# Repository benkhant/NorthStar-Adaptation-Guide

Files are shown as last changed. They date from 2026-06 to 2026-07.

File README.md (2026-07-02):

# NorthStar Adaptation Guide

> ⚠ Work in Progress: Hardware prototype complete. Documentation and software modules under active development.

### A Practical Guide to Building and Documenting a Low-Cost Open-Source Optical See-Through AR Headset

This repository documents the adaptation of Project North Star into a low-cost, reproducible, and well-documented optical see-through augmented reality (OST-AR) headset for computing education. The project establishes a transparent hardware and calibration foundation to support future development of interactive AR learning software.

Rather than focusing solely on hardware construction, this project emphasizes systematic documentation of the entire build process to lower financial and technical barriers to classroom deployment and future AR software development.

---

## Why This Project?

Commercial optical see-through AR headsets remain costly, proprietary, and difficult to deploy in classroom settings. This project aims to lower those barriers by providing a transparent, replicable, and well-documented alternative specifically tailored for computing education.

---

## Project Goals

- Adapt an open-source AR headset for educational use  
- Provide clear mechanical assembly documentation  
- Develop a repeatable optics calibration workflow  
- Publish a transparent bill of materials with cost breakdown  
- Enable reproducibility for educators and researchers  
- Establish a hardware foundation for interactive AR learning software
- Develop interactive AR learning activities for computer science education
- Evaluate the effectiveness of AR spatial visualization for teaching linked list operations

---

## Hardware Assembly

This guide is under active development. The headstrap assembly section will be added in a future update.

Mechanical assembly instructions are available here:

[Hardware Assembly Guide](docs/hardware-assembly.md)

Includes:
- Required components
- Heat insert installation
- Cable routing
- Display mounting
- Troubleshooting notes

---

## Optics Calibration

Calibration documentation is available here:

[Optics Calibration Guide](docs/optics-calibration.md)

Includes:
- Checkerboard-based alignment procedure
- Distortion correction process
- Representative calibration results
- Troubleshooting guide

---

## 3D-Printable Components

All printable components are located in:

[3D Printing Files](3d-printing-stl)

Each component is provided as an STL file for direct printing.

---

## Cost Transparency

This build prioritizes affordability using:
- Commodity electronics
- 3D-printed structural parts
- Open-source design

Filament costs are calculated using:
- Slicer-reported filament weight (grams)
- Cost per gram (based on spool price)
- Total print cost per component

A detailed bill of materials and cost breakdown spreadsheet will be published in this repository to support reproducibility.

---

## Current Status

- ✅ Hardware prototype constructed
- ✅ Optics calibration workflow established  
- 🚧 Mechanical documentation in progress  
- ✅ AR linked list deletion activity complete (Unity 2022)
- ✅ AR linked list deletion activity ported to Unity 6
- 🚧 Classroom pilot evaluation planned  

---

## Software: AR Linked List Deletion Activity

An interactive AR learning activity has been developed for visualizing 
linked list pointer operations using image tracking on an Android tablet.

Two versions of the activity are available in this repository:

| Version | Folder | Unity Version | Status |
|---|---|---|---|
| Stable (v1.0) | [`software/`](software/) | Unity 2022.3 LTS | ✅ Fully working, tagged `v1.0-deletion-activity` |
| Unity 6 Rebuild (v2.0) | [`LinkedListAR_Unity6/`](LinkedListAR_Unity6/) | Unity 6 (6000.0.73f1 LTS) | ✅ Fully working, tagged `v2.0-unity6-rebuild` |

### How It Works
Students physically manipulate printed marker cards on a table.
The tablet camera detects the cards and augments the scene with:
- Blue numbered nodes floating above each node card
- Orange dots above tail cards (outgoing pointers)
- Purple dots above head cards (incoming connections)
- Green arrows for correct pointer connections
- Red arrows for incorrect connections
- Live task instructions guiding students through the deletion task

### Activity Flow
1. Place all three node cards (10, 20, 30) on the table
2. Connect tail and head cards to build the starting list: 10 → 20 → 30
3. Delete node 20 by moving tail_10 to head_30, redirecting the pointer
4. The list updates to: 10 → 30

### Requirements
- Unity 2022.3 LTS (for `software/`) or Unity 6 6000.0.73f1 LTS (for `LinkedListAR_Unity6/`)
- AR Foundation
- Google ARCore XR Plugin
- Android tablet with ARCore support (tested on Samsung SM-X210)
- 7 printed marker cards (see `software/Assets/Markers/` or `LinkedListAR_Unity6/Assets/Markers/`)

### Unity 6 Migration Notes
The Unity 6 rebuild was created from scratch using Unity's AR Mobile template rather than migrating the Unity 2022 project directly. Key changes include:

- **ARCore added event fallback:** ARCore sometimes skips the `added` event for previously seen markers and fires `updated` directly. A fallback was added inside `UpdateMarker` to spawn objects on the spot if they don't exist yet, ensuring reliable detection across repeated app launches.
- **AR Mobile template:** Using the AR Mobile template instead of a generic Unity 6 project ensures correct renderer, AR Camera Background, OpenGLES3, and Tracked Pose Driver bindings are configured from the start.
- **API migration:** Updated from the deprecated `trackedImagesChanged` event to the new `trackablesChanged` UnityEvent introduced in AR Foundation 6.0.

### Current Status
- ✅ Image tracking with 7 marker cards
- ✅ Dynamic arrow drawing with color feedback
- ✅ Task instruction system
- ✅ Node deletion activity fully working on Unity 2022 and Unity 6
- 🚧 Esky HMD integration in progress
- 🚧 Classroom pilot evaluation planned

---

## Acknowledgements

Inspired by Project North Star.

Developed at Bucknell University.

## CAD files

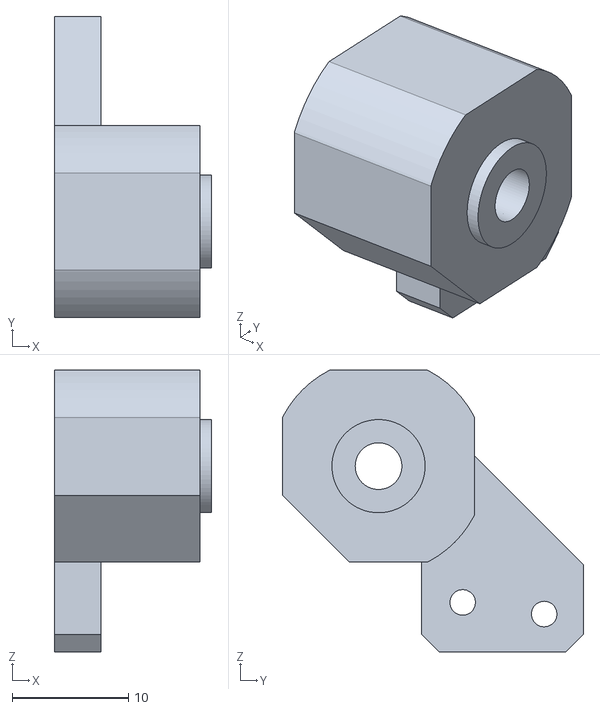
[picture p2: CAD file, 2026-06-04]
3d-printing-stl/strap_adapter_1_left.stl
13.5 x 25.8 x 24.2

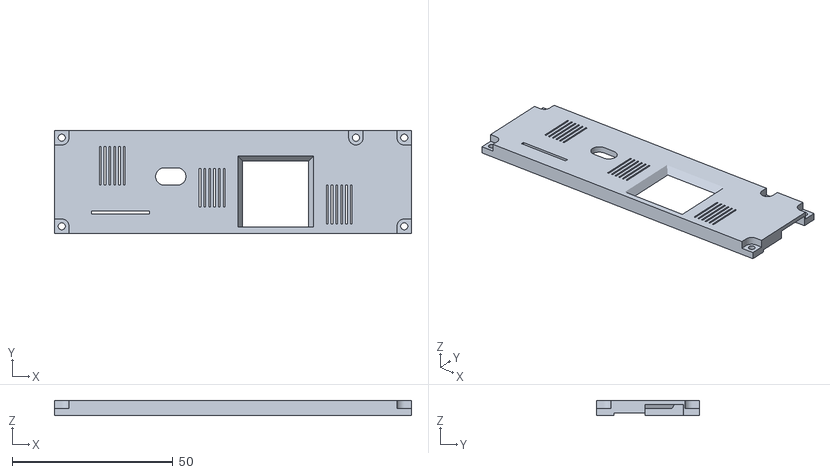
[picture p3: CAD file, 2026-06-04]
3d-printing-stl/electronic_lid.stl
110.9 x 32.0 x 4.80

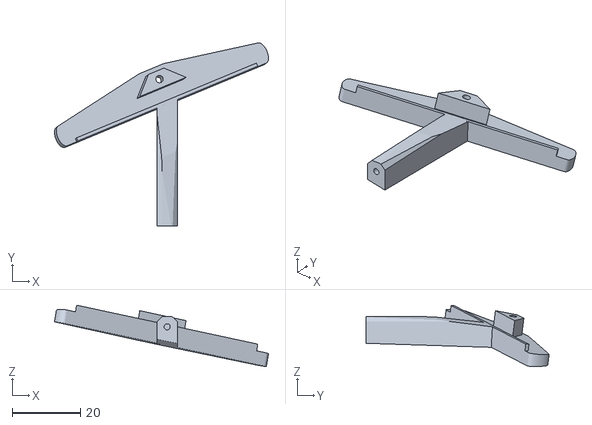
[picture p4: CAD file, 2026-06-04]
3d-printing-stl/display_holder_right.stl
62.7 x 53.7 x 17.9

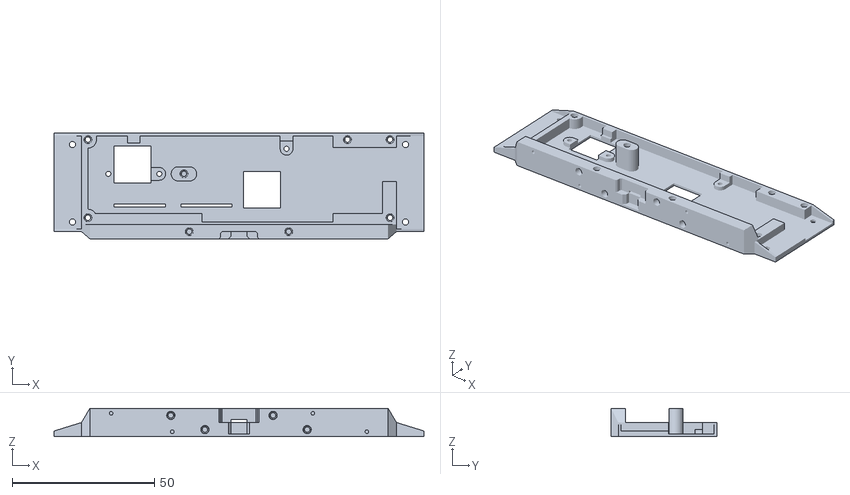
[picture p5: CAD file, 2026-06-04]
3d-printing-stl/electronic_bay.stl
130.2 x 37.2 x 10.0

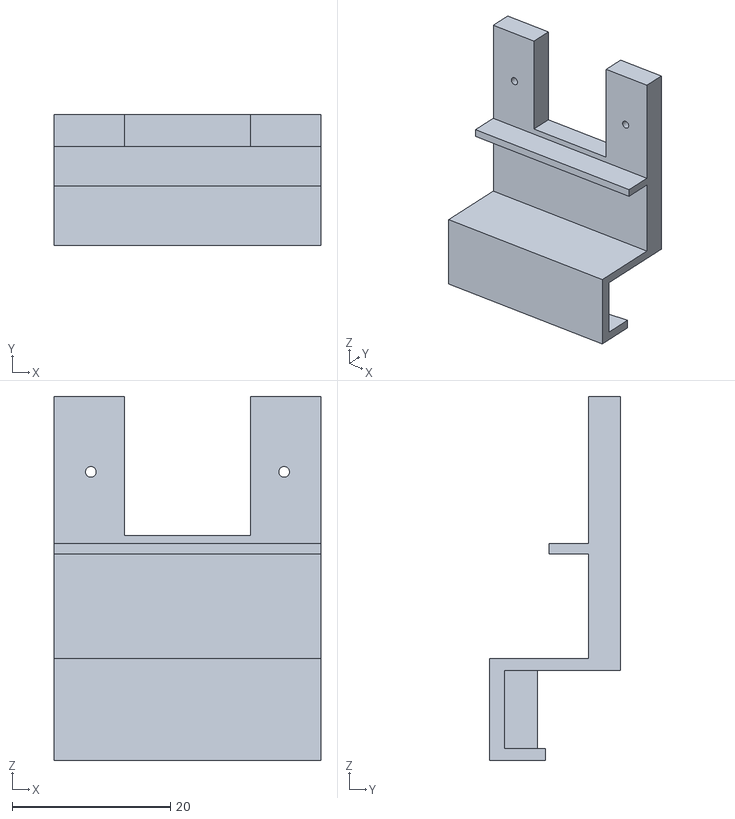
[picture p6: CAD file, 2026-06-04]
3d-printing-stl/t261_calibration_mount.obj
33.8 x 16.6 x 46.0

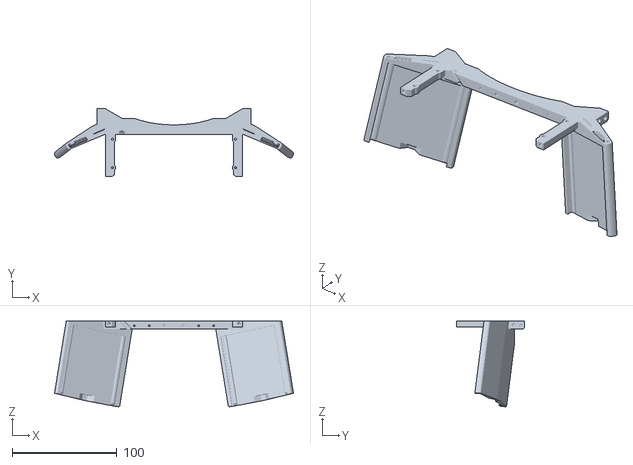
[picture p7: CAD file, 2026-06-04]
3d-printing-stl/optic_bracket.stl
228.0 x 64.8 x 81.6

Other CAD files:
3d-printing-stl/strap_adapter_1_right.stl
3d-printing-stl/display_holder_left.stl
LinkedListAR_Unity6/Assets/Plugins/LeapMotion/North Star/Models/AR headset Halo Small BOE unity optimized Rev 18 amazon stereo cameras.blend
LinkedListAR_Unity6/Assets/Plugins/LeapMotion/North Star/Models/AR headset Halo Small BOE unity optimized Rev 2 internal rigel.blend

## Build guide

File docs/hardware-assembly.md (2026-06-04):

# Hardware Assembly

## Parts List
- M2 heat inserts
- M2.5 heat inserts
- Two displays
- Electronic parts
- 6-pin 0.5 mm FFC cable

## Start of the Assembly

- Go to the 3d-printing-stl folder in the github to get the stl files for 3D printing 
- First, print the optic bracket stl file, then install M2 heat inserts into the optic bracket (red arrows below)
- Install M2.5 heat inserts (yellow arrows below)
  
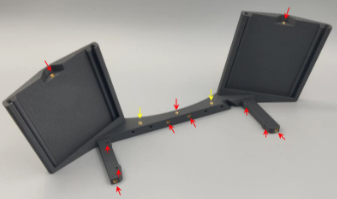
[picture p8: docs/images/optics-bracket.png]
  

- Connect the long ribbon cable to the adapter board (ensure the orientation of the ribbon cable is correct, see image below)
- Then, connect the display to the adapter board (ensure the orientation of the adapter board is correct, see image below)

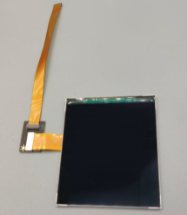
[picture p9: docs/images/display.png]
  

- Pull the ribbon cable through the hole in the optic bracket (red arrows in images below)
- Carefully fold the display cable and insert both the display and the adapter board into the slot of the optic bracket

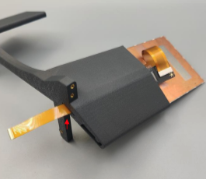
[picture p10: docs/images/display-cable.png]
  

- When inserting, you will need some force to make it all the way in

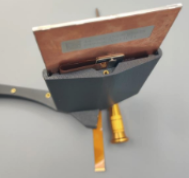
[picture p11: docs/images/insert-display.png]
  

- Use the display_holder_left stl file and display_holder_right stl file to print the display holder for left side and right side to secure the display with an M2x8 screw

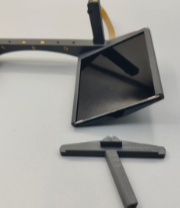
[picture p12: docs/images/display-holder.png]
  

- Repeat the steps from above for the second display

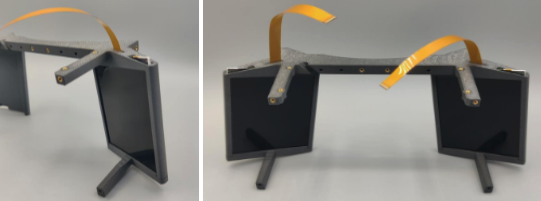
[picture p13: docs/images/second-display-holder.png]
  

- Use the electronic-bay stl file to print it out and install M2 heat inserts into it (see red arrows below)

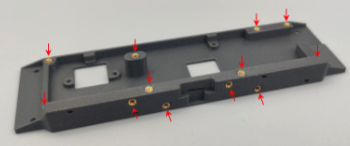
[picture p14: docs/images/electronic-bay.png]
  

- Connect the USB hub to the display driver using the 12-pin FFC cable
- Secure the USB hub with two M2x4 screws (do not secure the display driver yet)

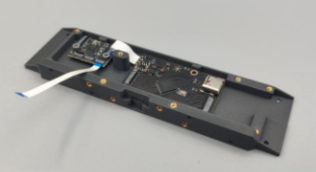
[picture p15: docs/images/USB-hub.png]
  

- Secure the electronics bay to the optic bracket with four M2x5 screws (see red arrows below)

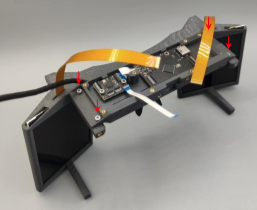
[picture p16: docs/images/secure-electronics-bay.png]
  

- Connect the left and right displays to the display driver (ensure the orientation of the ribbon cable is correct (see image below)

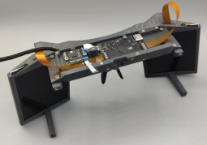
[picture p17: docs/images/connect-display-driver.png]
  

- Secure the display driver with an M2x5 screw

- Then use the electronic_lid stl file to print out the lid

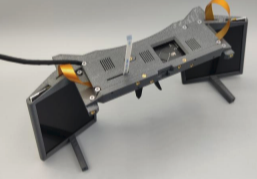
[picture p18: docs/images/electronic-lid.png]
  
  
- Then, carefully route all cables through the designated slots (see image above)
- Secure the lid with five M2x5 screws

- Secure the combiner with two M2x8 screws (see red arrows) and two M2 self-tapping screws (see yellow arrows)

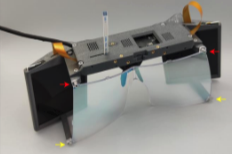
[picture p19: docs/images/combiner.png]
  

- Use the strap_adapter_1_left stl and strap_adapter_1_right stl to print out the straps
- Secure the left and right head strap adapters with M2x8 screws (see red arrows)

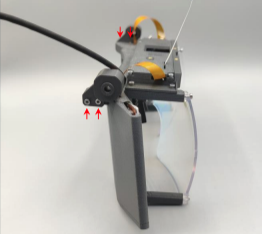
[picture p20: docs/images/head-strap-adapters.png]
  

## (continue head strap assembly)

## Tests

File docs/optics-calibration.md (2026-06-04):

# Optics Calibration

- Use the T261_calibration_mount stl file to print out the calibration mount
- Screw the T261 camera on the calibration mount as below
  
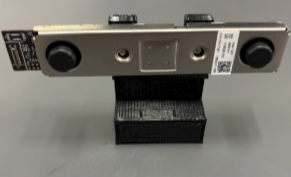
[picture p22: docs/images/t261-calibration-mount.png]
  

- I set up the headset and the T261 camera, as seen below, to calibrate

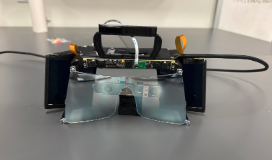
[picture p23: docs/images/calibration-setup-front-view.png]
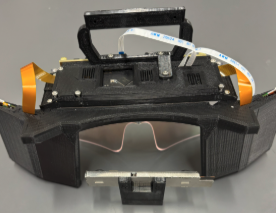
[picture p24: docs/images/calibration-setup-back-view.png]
   

- First, download the realsense-integration branch of the following repo: https://github.com/BryanChrisBrown/ProjectNorthStar/tree/realsense-integration, and you will get a ProjectNorthStar-realsense-integration file
- Setup python with the following dependencies: 
  - Pyrealsense2
  - opencv-contrib-python
  - numpy 

- In the ProjectNorthStar-realsense-integration file, go to Software → North Star Gen 2 → North Star Calibrator → captureGraycodes.py, then run the captureGraycodes.py 
- Make sure the T261 camera, which is screwed onto the mount, is looking through the headset where the users’ eyes will be
- On line 44 of captureGraycodes.py, you will want the X value (1920) to be your main monitor’s width in pixels (cv2.moveWindow (“Graycode Viewport”, 1920, 0))
- It also helps to place a piece of cloth over the headset to shield the cameras and headset from ambient light, as shown below

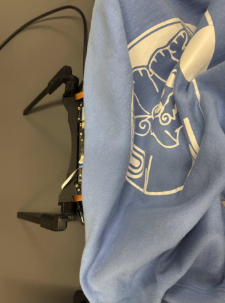
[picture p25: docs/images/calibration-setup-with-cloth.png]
  

- Then run calibrateGraycodes.py in the ProjectNorthStar-realsense-integration file → Software → North Star Gen 2 → North Star Calibrator 
- From running that, you will get something like below

  

- Paste the above output into this website: https://www.shadertoy.com/view/wsscD4 called Shadertoy to check for alignment
- Also, make sure that the headset is plugged in and displaying imagery from your desktop
- Running calibrateGraycodes.py will display a sequence of gray codes on your North Star headset look something like below

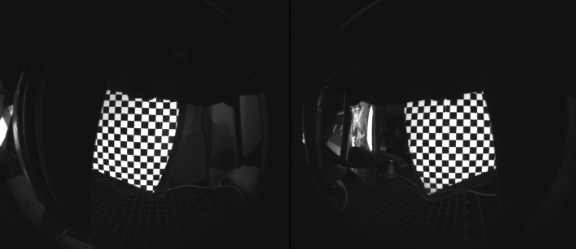
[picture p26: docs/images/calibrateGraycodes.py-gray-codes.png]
  

- After pasting the output into the Shadertoy website and if you compile it, you will see something like this below  (black and white chess board)

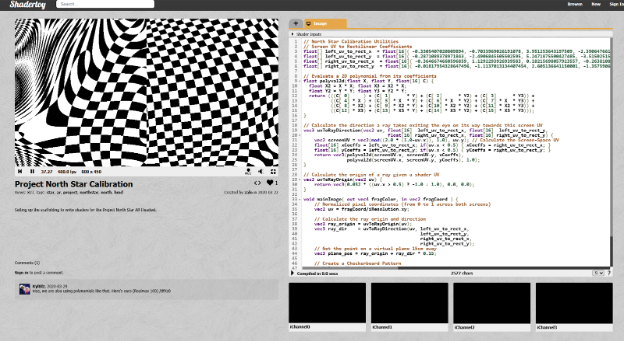
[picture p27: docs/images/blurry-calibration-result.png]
  

- That blurry black and white chessboard represents a bad calibration result
- The following was my final calibration result

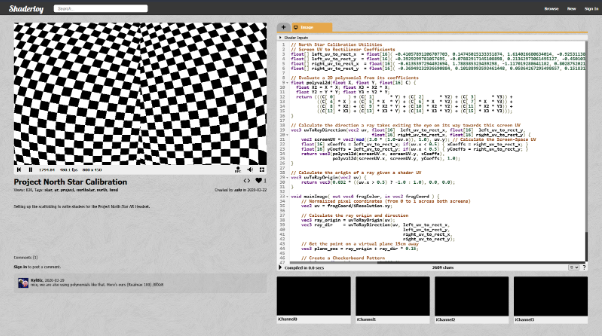
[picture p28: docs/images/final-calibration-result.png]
  

- Also note that dust on the display and lenses can affect calibration result

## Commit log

2026-06-04 Local project files before merge
    [display_holder_left.stl, display_holder_right.stl, electronic_bay.stl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]
2026-06-10 partial working deletetion activity - stuck at the remove node 20 stage
2026-06-11 adjusted timer for the last task
2026-07-16 Initial commit of full ProjectEsky + MRTK integration with Unity 6 migration, native library fixes, and working AR activity after esky import
    [AR headset Halo Small BOE unity optimized Rev 18 amazon stereo cameras.blend, AR headset Halo Small BOE unity optimized Rev 2 internal rigel.blend]
2026-07-28 Fix ArUco marker tracking on Esky/T265 camera
    Corrected the image decoding: the native camera library reports
    image dimensions and format incorrectly (reports double resolution,
    grayscale instead of BGRA color). Added logic to derive the real
    width, height, and channel count directly from the data itself.
    Fixed frame tearing by switching from a raw memory pointer callback
    to reading the camera image through a properly-synchronized Unity
    RenderTexture instead, eliminating a race condition with the native
    capture thread.
    Marker detection is now working reliably, detecting up to 10 markers
    per frame, and correctly updates a test
    object's position in real time as the marker board moves.
2026-09-04 Switch to per-marker tracking so each marker spawns its own node
    Instead of treating the whole board as one fixed layout, each marker
    now gets tracked individually and spawns whatever prefab it's mapped
    to in the Inspector. Tested with real, individually cut markers.
    Objects still flicker sometimes, added a grace period before hiding
    a marker to try to help, but the flickering isn't fully resolved and
    the exact cause isn't confirmed yet.
2026-09-04 Connect Esky marker tracking to the real linked list task logic
    Wired the per-marker tracking system into TaskManager, the same task
    logic already used on the tablet version. Added a card name field to
    each marker mapping (node_10, tail_20, etc.) so spawned objects get
    sorted into the node/tail/head dictionaries TaskManager expects.
    Also added a small null-check in TaskManager so it doesn't crash when
    TrackedImageInfo (an AR Foundation-specific reference) isn't set,
    which is the case in the Esky version but not the tablet version.
    Created TaskManager and ArrowManager in the Esky scene and wired them
    together. So far only tested the first step: showing all three node
    markers correctly updat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
2026-09-04 Wire up tail/head markers and connect ArrowManager
    Tail and head markers now spawn simple colored dots at runtime,
    orange for tails, purple for heads, same as the tablet version. No
    prefab needed for these, the code just checks if the card name
    starts with tail_ or head_.
    Also found that ArrowManager has its own UpdateMarkers method that
    was never getting called from the Esky side, so arrows just weren't
    showing up. Added that call and now they draw and color correctly
    between tail and head markers.
    So far I've tested placing the node markers and connecting one tail
    to its head marker, and the arrow shows up correctly. Still need to
    test the rest: the deletion step, and the full sequence e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
2026-09-11 Adjust marker tracking settings
    Turned off the setting that skipped every other frame, since checking
    the actual FPS showed the game was already running fine (70-80fps),
    so skipping frames wasn't really helping.
    Also shortened how long a marker stays visible after the camera loses
    it, from 10 frames down to 3, since the old number was based on a
    slower frame rate than what we're actually getting.
    Still tuning this, right now it's running at 40-50fps with detection
    happening every frame. Haven't tested the full activity yet.
2026-09-11 Upgrade project to Unity 6.3 LTS
    Upgraded from 6000.0.73f1 to 6.3 LTS. Hit a compile error right away,
    some old code had [SerializeField] on a property instead of a field,
    which older Unity apparently let slide but 6.3 doesn't. Fixed that
    (there were 14 of the same mistake in one file).
    A handful of unrelated prefabs (some Oculus MRTK stuff, old
    calibration rigs) show import warnings now, but the project still
    compiles and runs, and I confirmed the marker tracking and node
    spawning still work on this version.
2026-09-16 Save current Unity project state
2026-10-22 Set up project on new laptop and switch to Unity WebRTC
    Replaced Microsoft MR WebRTC with com.unity.webrtc since it broke after the Unity 6.3 upgrade. Fixed the stale WebRTC reference in MainScripts.asmdef, swapped in the realsense2.dll from SDK 2.53.1, and moved to Unity 6000.3.25f1.
2026-10-28 Switch North Star eye materials to URP Unlit so the displays render
2026-11-06 Hide the camera preview so it does not block the headset view
2026-11-11 Add FPS logger and a switch for per frame tracking logs

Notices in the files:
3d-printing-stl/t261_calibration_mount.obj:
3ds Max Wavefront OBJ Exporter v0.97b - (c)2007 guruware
